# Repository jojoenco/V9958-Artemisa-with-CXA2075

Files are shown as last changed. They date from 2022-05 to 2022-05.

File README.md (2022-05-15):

# V9958-Artemisa-MSX-with-CXA2075
Video extension Artemisa MSX V9958 with CXA2075 (Composiet)

V9958 for Artemisa(Made By Alvaro Polo) [Artemisa MSX Project](https://github.com/apoloval/artemisa)

I made an Video Extension for the Artemisa with an V9958 and en CXA2075(for Composiet out).
Which works fine in MSX1 modus, however I also want it to work with MSX2 Modus (screen4 to 8).
Have tried a cartridge with a lot of rom's for V9958 and an MSX2 Rom's on the mainboard, but that did not work out.

For R12 you have to use a Resistor exacly 85.5 Ohm, I ordered a few but after a few mistakes I had none, 
so measured 82 Ohm resistors until I found 82,5 Ohm, and works fine.
The 2K61 I could not find measured so used exact version.

I did not test de S-video and de VGA.
And the Composiet picture has a litte noise.




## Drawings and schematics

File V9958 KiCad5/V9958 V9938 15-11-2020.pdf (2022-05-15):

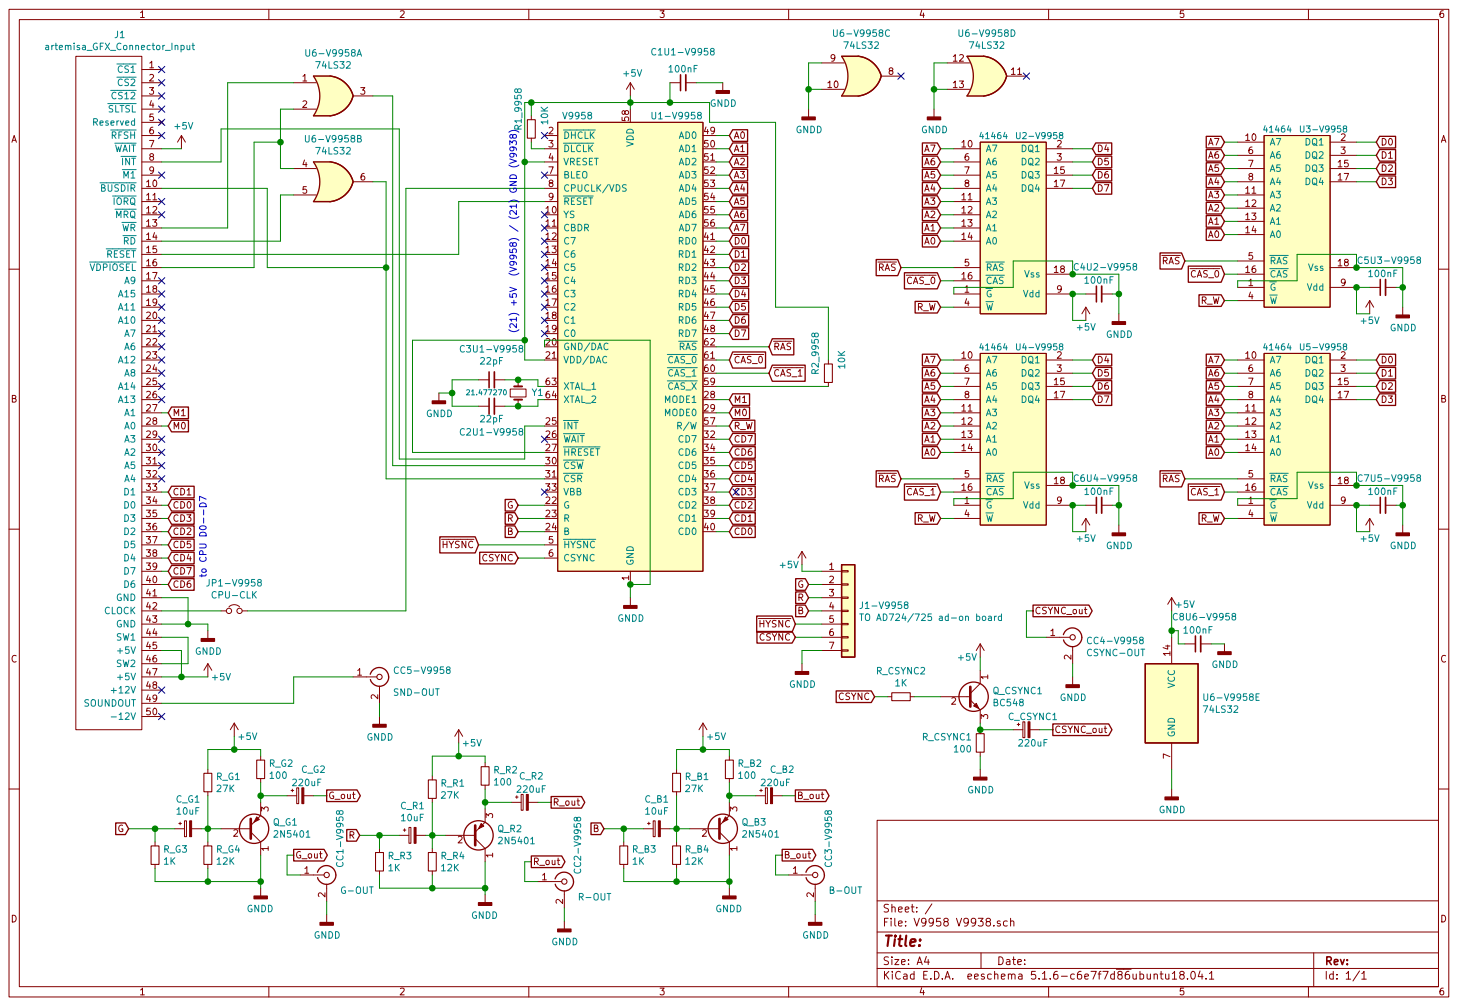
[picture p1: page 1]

1 YS 10 CBDR 11 C7 12 C6 13 C5 14 C4 15 C3 16 C2 17 C1 18 C0 19 DHCLK 2 GND/DAC 20 VDD/DAC 21 G

2 CC5-V9958 SND-OUT GNDD GNDD GNDD

Id: 1/1 Title: File: V9958 V9938.sch Sheet: / R_R2

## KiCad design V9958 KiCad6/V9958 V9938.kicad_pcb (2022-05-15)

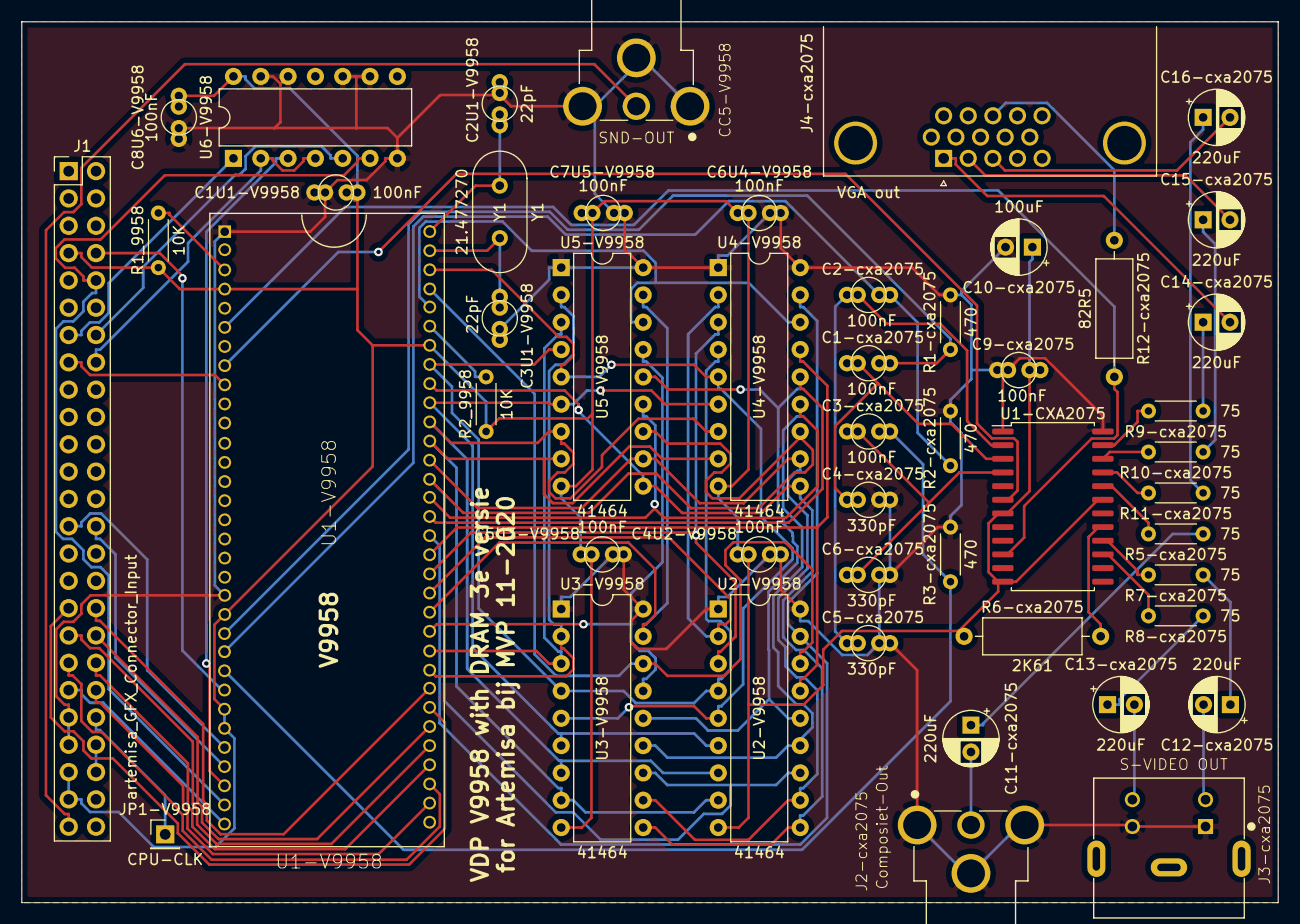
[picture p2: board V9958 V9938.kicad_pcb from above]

Board: 2 copper layers, 116.8 x 81.9 mm, 49 parts (0 on the bottom side), 74 nets.

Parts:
C1-cxa2075, C1U1-V9958, C2-cxa2075, C3-cxa2075, C4U2-V9958, C5U3-V9958, C6U4-V9958, C7U5-V9958, C8U6-V9958, C9-cxa2075: 100nF; C_dual_hole_radial
C2U1-V9958, C3U1-V9958: 22pF; C_dual_hole_radial
C4-cxa2075, C5-cxa2075, C6-cxa2075: 330pF; C_dual_hole_radial
C10-cxa2075: 100uF; CP_Radial_D5.0mm_P2.50mm
C11-cxa2075, C12-cxa2075, C13-cxa2075, C14-cxa2075, C15-cxa2075, C16-cxa2075: 220uF; CP_Radial_D5.0mm_P2.50mm
CC5-V9958: SND-OUT; CUI_RCJ-013
J1: artemisa_GFX_Connector_Input; PinHeader_2x25_P2.54mm_Vertical
J2-cxa2075: Composiet-Out; CUI_RCJ-013
J3-cxa2075: S-VIDEO OUT; CUI_MD-40SM
J4-cxa2075: VGA out; DSUB-15-HD_Female_Horizontal_P2.29x1.98mm_EdgePinOffset8.35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
JP1-V9958: CPU-CLK; PinHeader_1x01_P2.54mm_Vertical
R1-cxa2075, R2-cxa2075, R3-cxa2075: 470; R_Axial_DIN0204_L3.6mm_D1.6mm_P5.08mm_Horizontal
R1_9958, R2_9958: 10K; R_Axial_DIN0204_L3.6mm_D1.6mm_P5.08mm_Horizontal
R5-cxa2075, R7-cxa2075, R8-cxa2075, R9-cxa2075, R10-cxa2075, R11-cxa2075: 75; R_Axial_DIN0204_L3.6mm_D1.6mm_P5.08mm_Horizontal
R6-cxa2075: 2K61; R_Axial_DIN0309_L9.0mm_D3.2mm_P12.70mm_Horizontal
R12-cxa2075: 82R5; R_Axial_DIN0309_L9.0mm_D3.2mm_P12.70mm_Horizontal
U1-CXA2075: CXA2075; SOP-24_7.5x15.4mm_P1.27mm
U1-V9958: V9958; DIP64-S
U2-V9958, U3-V9958, U4-V9958, U5-V9958: 41464; DIP-18_W7.62mm
U6-V9958: 74LS32; DIP-14_W7.62mm
Y1: 21.477270; Crystal_HC49-U_Vertical

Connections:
1<->cxa2075: C1U1-V9958.1, C4U2-V9958.1, C5U3-V9958.1, C6U4-V9958.1, C7U5-V9958.1, C8U6-V9958.1, C9-cxa2075.2, C10-cxa2075.1, J1.7, J1.45, J1.47, R1_9958.1, R2_9958.1, R6-cxa2075.1, U1-CXA2075.7, U1-CXA2075.12, U1-CXA2075.19, U1-V9958.4, U1-V9958.21, U1-V9958.26, U1-V9958.27, U1-V9958.58, U2-V9958.9, U3-V9958.9, U4-V9958.9, U5-V9958.9, U6-V9958.14
2<->cxa2075: C1-cxa2075.2, R1-cxa2075.1, U1-V9958.22
3<->cxa2075: C2-cxa2075.2, R2-cxa2075.1, U1-V9958.23
4<->cxa2075: C3-cxa2075.2, R3-cxa2075.1, U1-V9958.24
6<->cxa2075: R12-cxa2075.2, U1-CXA2075.10, U1-V9958.6
7<->cxa2075: C1U1-V9958.2, C2U1-V9958.1, C3U1-V9958.1, C4-cxa2075.2, C4U2-V9958.2, C5-cxa2075.2, C5U3-V9958.2, C6-cxa2075.2, C6U4-V9958.2, C7U5-V9958.2, C8U6-V9958.2, C9-cxa2075.1, C10-cxa2075.2, CC5-V9958.2, J1.41, J1.43, J2-cxa2075.2, J3-cxa2075.1, J3-cxa2075.2, R1-cxa2075.2, R2-cxa2075.2, R3-cxa2075.2, U1-CXA2075.1, U1-CXA2075.24, U1-V9958.1, U1-V9958.20, U2-V9958.1, U2-V9958.18, U3-V9958.1, U3-V9958.18, U4-V9958.1, U4-V9958.18, U5-V9958.1, U5-V9958.18, U6-V9958.7, U6-V9958.9, U6-V9958.10, U6-V9958.12, U6-V9958.13
8<->cxa2075: U1-CXA2075.6, U1-V9958.8
A0: U1-V9958.49, U2-V9958.14, U3-V9958.14, U4-V9958.14, U5-V9958.14
A1: U1-V9958.50, U2-V9958.13, U3-V9958.13, U4-V9958.13, U5-V9958.13
A2: U1-V9958.51, U2-V9958.12, U3-V9958.12, U4-V9958.12, U5-V9958.12
A3: U1-V9958.52, U2-V9958.11, U3-V9958.11, U4-V9958.11, U5-V9958.11
A4: U1-V9958.53, U2-V9958.8, U3-V9958.8, U4-V9958.8, U5-V9958.8
A5: U1-V9958.54, U2-V9958.7, U3-V9958.7, U4-V9958.7, U5-V9958.7
A6: U1-V9958.55, U2-V9958.6, U3-V9958.6, U4-V9958.6, U5-V9958.6
A7: U1-V9958.56, U2-V9958.10, U3-V9958.10, U4-V9958.10, U5-V9958.10
CD0: J1.34, U1-V9958.40
CD1: J1.33, U1-V9958.39
CD2: J1.36, U1-V9958.38
CD3: J1.35, U1-V9958.37
CD4: J1.38, U1-V9958.36
CD5: J1.37, U1-V9958.35
CD6: J1.40, U1-V9958.34
CD7: J1.39, U1-V9958.32
D0: U1-V9958.41, U3-V9958.2, U5-V9958.2
D1: U1-V9958.42, U3-V9958.3, U5-V9958.3
D2: U1-V9958.43, U3-V9958.15, U5-V9958.15
D3: U1-V9958.44, U3-V9958.17, U5-V9958.17
D4: U1-V9958.45, U2-V9958.2, U4-V9958.2
D5: U1-V9958.46, U2-V9958.3, U4-V9958.3
D6: U1-V9958.47, U2-V9958.15, U4-V9958.15
D7: U1-V9958.48, U2-V9958.17, U4-V9958.17
M0: J1.28, U1-V9958.29
M1: J1.27, U1-V9958.28
unnamed: C1-cxa2075.1, C4-cxa2075.1, U1-CXA2075.3
unnamed: C2-cxa2075.1, C5-cxa2075.1, U1-CXA2075.2
unnamed: C2U1-V9958.2, U1-V9958.64, Y1.1
unnamed: C3-cxa2075.1, C6-cxa2075.1, U1-CXA2075.4
unnamed: C3U1-V9958.2, U1-V9958.63, Y1.2
unnamed: C11-cxa2075.1, R5-cxa2075.1
unnamed: C11-cxa2075.2, J2-cxa2075.1
unnamed: C12-cxa2075.1, R7-cxa2075.1
unnamed: C12-cxa2075.2, J3-cxa2075.3
unnamed: C13-cxa2075.1, R8-cxa2075.1
unnamed: C13-cxa2075.2, J3-cxa2075.4
unnamed: C14-cxa2075.1, R9-cxa2075.1
unnamed: C14-cxa2075.2, J4-cxa2075.1
unnamed: C15-cxa2075.1, R10-cxa2075.1
unnamed: C15-cxa2075.2, J4-cxa2075.2
unnamed: C16-cxa2075.1, R11-cxa2075.1
unnamed: C16-cxa2075.2, J4-cxa2075.3
unnamed: CC5-V9958.1, J1.49
unnamed: J1.8, U1-V9958.25
unnamed: J1.10, U1-V9958.31, U6-V9958.6
unnamed: J1.13, U6-V9958.1
unnamed: J1.14, U6-V9958.5
unnamed: J1.15, U1-V9958.9
unnamed: J1.16, U6-V9958.2, U6-V9958.4
unnamed: J1.42, JP1-V9958.1
unnamed: J1.44, J1.46
unnamed: J4-cxa2075.13, R12-cxa2075.1
unnamed: R1_9958.2, U1-V9958.3
unnamed: R2_9958.2, U1-V9958.59
unnamed: R5-cxa2075.2, U1-CXA2075.20
unnamed: R6-cxa2075.2, U1-CXA2075.17
unnamed: R7-cxa2075.2, U1-CXA2075.16
unnamed: R8-cxa2075.2, U1-CXA2075.15
unnamed: R9-cxa2075.2, U1-CXA2075.23
unnamed: R10-cxa2075.2, U1-CXA2075.22
unnamed: R11-cxa2075.2, U1-CXA2075.21
unnamed: U1-V9958.30, U6-V9958.3
R_W: U1-V9958.57, U2-V9958.4, U3-V9958.4, U4-V9958.4, U5-V9958.4
~CAS_0: U1-V9958.61, U2-V9958.16, U3-V9958.16
~CAS_1: U1-V9958.60, U4-V9958.16, U5-V9958.16
~RAS: U1-V9958.62, U2-V9958.5, U3-V9958.5, U4-V9958.5, U5-V9958.5
